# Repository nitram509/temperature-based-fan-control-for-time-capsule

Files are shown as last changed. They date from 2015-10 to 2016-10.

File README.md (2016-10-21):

# Temperature Based Fan Control For Time Capsule

An Arduino based controller board (powered just via USB) to automatically adjust
a fan to cool down an Apple Time Capsule.
Because: There is hope, that a cooled hard drive lives longer ;-)

See also Google's study [Failure Trends in a Large Disk Drive Population](http://static.googleusercontent.com/media/research.google.com/en/archive/disk_failures.pdf)

##### Community Links

[Hackaday project site](https://hackaday.io/project/16555-temperature-based-fan-control)

### Bill Of Material

* 1x Arduino Nano (Atmege 328P, 16MHz)
* 2x Temperature Sensor LM35, To-92 package e.g. [LM35DZ on Ebay](http://www.ebay.com/sch/i.html?_nkw=LM35DZ) (0°C..100°C)
   * used together with a R-C Damper, see [manual's Figure 4](http://www.watterott.com/download/LM35.pdf)
* 1x Mosfet (which works at logic level), e.g. IRLR/U120NPbF (LU120N, MOSFET N-LogL TO-251AA 100V 10A)
* 2x Resistor: 75 Ohm
* 1x Resistor: 220 Ohm
* 1x Resistor: 10k Ohm
* 2x Condensator: 1 microFarad
* 1x Diode: e.g. 1N4001
* 1x 3-pin Molex female connector (fit's for fan)
* 1x 5V to 12V DC-DC boost module (StepUp converter), e.g. [XL6009 on Ebay](http://www.ebay.com/sch/i.html?_nkw=XL6009)
* 1x 40x40mm Fan, 12V, e.g. Noiseblocker BlackSilentFan XM1

##### Remarks, what fan to choose

During testing I used an ordinary 12V fan (which I had on spare).
The PWN control worked very well.
BUT when I used the Noiseblocker BlackSilentFan XM1, the fan emmit annoying 'piep' noise.
I think this is related to the XM1's internal electronic, which somehow affects the PWM signal.
My bottom line: For the XM1 speed controll, I just use on/off semantics and no intermediate speed.

### Schematics

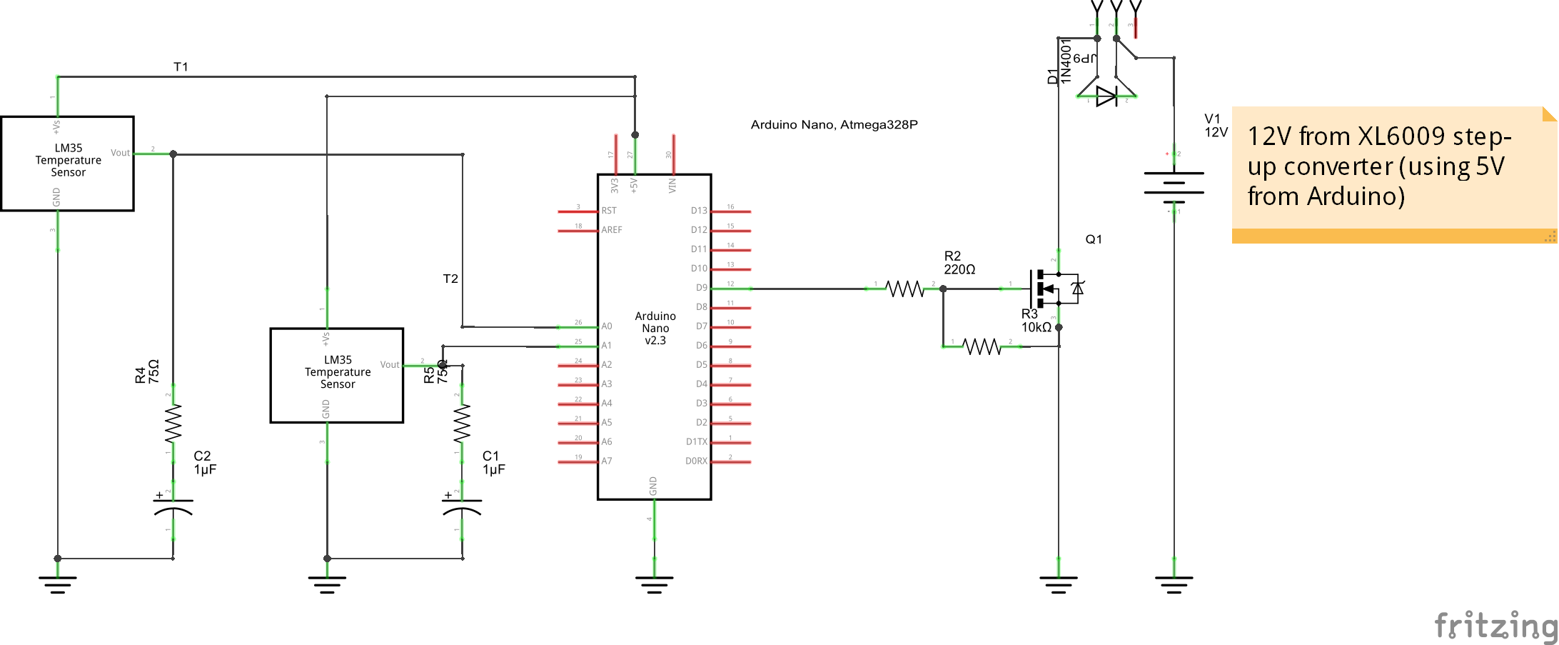
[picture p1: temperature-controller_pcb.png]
PCB


### Pictures

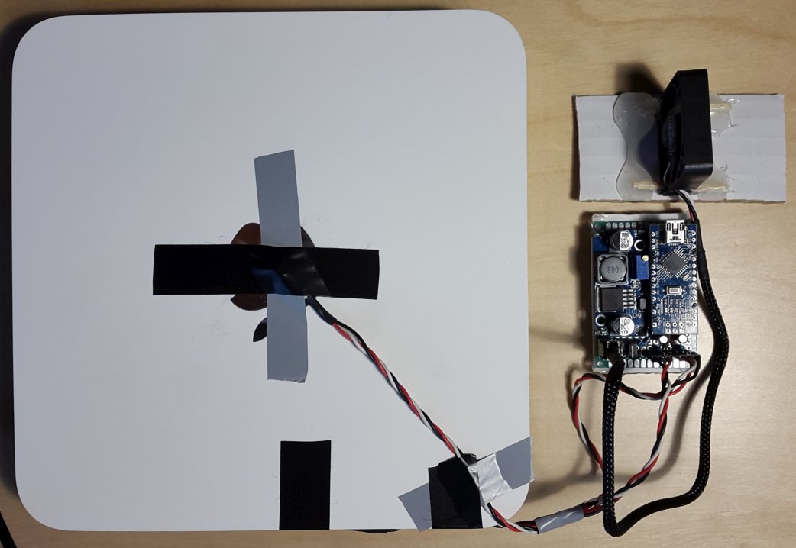
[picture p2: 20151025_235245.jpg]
PCB and Time Capsule


### Record temperature time series and visualize it

To adjust your own setup, I recommend to record a time series and figure out your own thresholds.
See [howto-timeseries.md](howto-timeseries.md) for details how to record and visualize such time series.

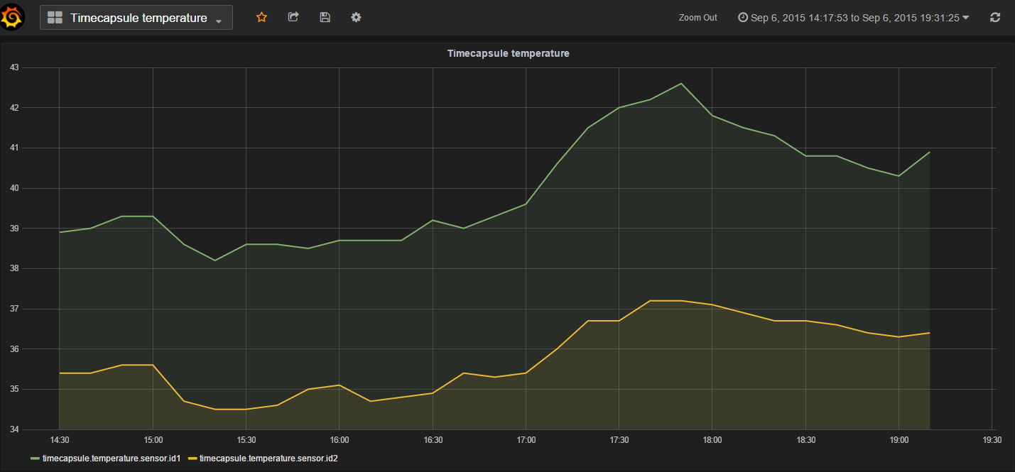
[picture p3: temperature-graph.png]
example temperature

This time series shows how temperature changes over time.
Circa 17:00 the backup was started, so the temperature increased.

##### License

[The MIT License (MIT)](https://opensource.org/licenses/MIT)

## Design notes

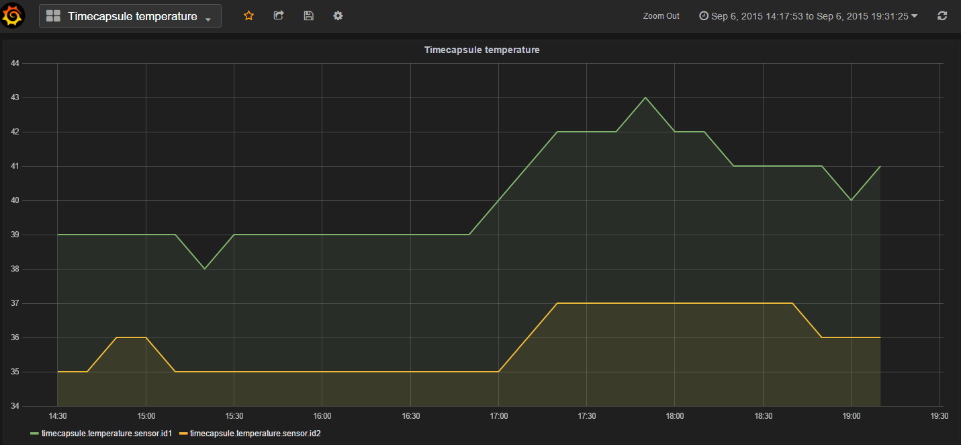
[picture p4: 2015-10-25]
temperature-graph-rounded.png

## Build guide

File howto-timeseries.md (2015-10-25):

# Recording temperature values (a.k.a. monitoring)

Connect Arduino to your PC and adjust the device name in ```monitor-tty.py```.

````
python monitor-tty.py > log.csv
````

# Visualisation

## Using Graphite

https://hub.docker.com/r/hopsoft/graphite-statsd/

### Run Graphite

````
docker run -d --name graphite --restart=always -p 80:80 -p 2003:2003 -p 8125:8125/udp -p 8126:8126 hopsoft/graphite-statsd
````

## Using Grafana

https://hub.docker.com/r/grafana/grafana/

### Run Grafana

````
docker run -d -p 3000:3000 -e "GF_SERVER_ROOT_URL=http://localhost:3000"  -e "GF_SECURITY_ADMIN_PASSWORD=secret"  grafana/grafana
````

Hint: Add a data source ```http://localhost``` with direct connection type (a.k.a. no proxy).

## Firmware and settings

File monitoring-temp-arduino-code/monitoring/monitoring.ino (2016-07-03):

/**************************************************************/
/* define pin setup, what sensor/fan is connected to what pin */
/**************************************************************/

int LM35_1_PIN = A0;
int LM35_2_PIN = A1;
int FAN_PWM_PIN = 9;

// only needed when measuring temperature time series values
#define SEND_TEMP_VALUES_TO_HOST true
#define SEND_TO_HOST_INTERVALL_IN_MILLIS 6000

#define SENSOR_1_TEMP_THRESHOLD_in_CELCIUS 41.0
#define SENSOR_2_TEMP_THRESHOLD_in_CELCIUS 37.0

/***************************************************************/

#define RING_BUFFER_SIZE 30
#define INVALID_VALUE -273.0
#define AVERAGE_INTERVAL_IN_MILLIS 60000 // e.g. one minute = 60000

/***************************************************************/

struct TemperatureRingBuffer {
    float values[RING_BUFFER_SIZE];
    int writeIndex = 0;
};

TemperatureRingBuffer tempRingBuf_1;
TemperatureRingBuffer tempRingBuf_2;
unsigned long lastSendMillis = 0;
unsigned long lastRecordedMillis = 0;

/**************************************************************/

float readTemperatureInCelcius(int lm35_pin) {
    return (5.0 * 100.0 * analogRead(lm35_pin)) / 1024;
}

void buffer_write(TemperatureRingBuffer *tempRingBuf, float value) {
    tempRingBuf->values[tempRingBuf->writeIndex] = value;
    tempRingBuf->writeIndex = (tempRingBuf->writeIndex++) % RING_BUFFER_SIZE;
}

void initRingBuffer(TemperatureRingBuffer *tempRingBuf) {
    for (int i=0; i<RING_BUFFER_SIZE; i++) {
        tempRingBuf->values[i] = INVALID_VALUE;
    }
}

float averageValues(TemperatureRingBuffer *tempRingBuf) {
    float sum = 0.0;
    int numberOfValidValues = 0;
    for (int i=0; i<RING_BUFFER_SIZE; i++) {
        if (tempRingBuf->values[i] != INVALID_VALUE) {
            numberOfValidValues ++;
            sum += tempRingBuf->values[i];
        }
    }
    return sum / (float)numberOfValidValues;
}

void sendValuesToHost() {
    unsigned long currentMillis = millis();
    bool isIntervalPassed = (currentMillis - lastSendMillis) > (unsigned long)SEND_TO_HOST_INTERVALL_IN_MILLIS;
    if ((unsigned long)0 == lastSendMillis || isIntervalPassed) {
        lastSendMillis = currentMillis;

        Serial.print("Sensor (1) ");
        Serial.print(averageValues(&tempRingBuf_1), 1);
        Serial.println(" Grad Celsius");

        Serial.print("Sensor (2) ");
        Serial.print(averageValues(&tempRingBuf_2), 1);
        Serial.println(" Grad Celsius");

        Serial.println("");
    }
}

void adjustFanSpeed() {
    float lastIntervalTempAverage_1 = averageValues(&tempRingBuf_1);
    float lastIntervalTempAverage_2 = averageValues(&tempRingBuf_2);
    if (lastIntervalTempAverage_1 > SENSOR_1_TEMP_THRESHOLD_in_CELCIUS
       || lastIntervalTempAverage_2 > SENSOR_2_TEMP_THRESHOLD_in_CELCIUS) {
        analogWrite(FAN_PWM_PIN, 255);
    } else {
        analogWrite(FAN_PWM_PIN, 0);
    }
}

void recordSensorMeasurements() {
    unsigned long currentMillis = millis();
    bool isIntervalPassed = (currentMillis - lastRecordedMillis) > ((unsigned long)AVERAGE_INTERVAL_IN_MILLIS / (unsigned long)RING_BUFFER_SIZE);
    if ((unsigned long)0 == lastRecordedMillis || isIntervalPassed) {
        lastRecordedMillis = currentMillis;
        buffer_write(&tempRingBuf_1, readTemperatureInCelcius(LM35_1_PIN));
        buffer_write(&tempRingBuf_2, readTemperatureInCelcius(LM35_2_PIN));
     }
}

void setup() {
    if (SEND_TEMP_VALUES_TO_HOST) {
        Serial.begin(9600);
    }

    pinMode(FAN_PWM_PIN, OUTPUT);

    initRingBuffer(&tempRingBuf_1);
    initRingBuffer(&tempRingBuf_2);
}

void loop() {
    recordSensorMeasurements();
    adjustFanSpeed();
    if (SEND_TEMP_VALUES_TO_HOST) {
        sendValuesToHost();
    }
}

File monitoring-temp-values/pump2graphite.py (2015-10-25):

#!/usr/bin/python
# -*- coding: utf-8 -*-

import socket

LOG_FIELD_DELIMITER = ';'
CARBON_SERVER = '127.0.0.1'
CARBON_PORT = 2003
DO_TEMPERATURE_ROUNDING = False

def readLog():
    f = file('log.csv', 'r')
    result = []
    for line in f.readlines():
        line = line.strip()
        line = line.replace(',', '.')
        (time, id, temp) = line.split(LOG_FIELD_DELIMITER)
        time = time.strip().replace(LOG_FIELD_DELIMITER, '')
        id = id.strip().replace(LOG_FIELD_DELIMITER, '')
        temp = temp.strip().replace(LOG_FIELD_DELIMITER, '')
        result.append((time, id, temp))
    f.close()
    return result


def pump2graphite(logRecords):
    conn = socket.create_connection((CARBON_SERVER, CARBON_PORT))
    for rec in logRecords:
        (time, id, temp) = rec
        time = long(round(float(time)))
        if (DO_TEMPERATURE_ROUNDING):
            temp = long(round(float(temp)))
        else:
            temp = float(temp)
        message = str('timecapsule.temperature.sensor.id%s %s %s\n' % (id, temp, time))
        conn.send(message)
    conn.close()
    print "Done."


if __name__ == "__main__":
    logRecords = readLog()
    while len(logRecords) > 0:
        buffer = []
        i = 100
        while i > 0 and len(logRecords) > 0:
            buffer.append(logRecords.pop())
            i -= 1
        pump2graphite(buffer)

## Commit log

2015-10-25 added pump2graphite.py
2016-07-03 add second log file
    [log2.csv]
2016-07-03 add pictures and refactored code to use ringBuffer
    [temperature-controller.fzz]
2016-07-03 add BOM
2016-07-03 implement threshold for activating fan
2016-07-03 more clean code and fix interval averaging
    [monitoring.ino]
